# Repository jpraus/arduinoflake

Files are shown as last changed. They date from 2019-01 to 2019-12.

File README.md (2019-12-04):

# Arduinoflake

Arduinoflake is an awesome winter decoration that will light up every dark night. It is no ordinary decoration. This frozen looking beauty is Arduino compatible and can be programmed to do whatever you want to! It features a capacitive touch button which let you interact with it. Last but not least it is **open-source**.

Arduinoflakes

## Features

- 30 LEDs grouped into 18 independent segments
- touch button for interactions
- ATmega8 Arduino compatible microprocessor
- micro USB interface for programming (CH340 USB-to-UART)
- AVR ISP interface for bootloader flashing
- runs up to 12 hours on a single CR2032 battery

## Building your Arduinoflake

The easiest way how to get your own snowflake is to order a DIY kit on my [Tindie Store](https://www.tindie.com/products/jiripraus/arduinoflake/). Kit contains professionally manufactured PCBs by PCBway and all compatible components needed to assemble a fully functional Arduinoflake.

The second option is to manufacture the PCB and get all necessary parts yourself. Arduinoflake is Open-Source. [Schematic](doc/schematic_rev4.png) and [Gerber files](gerber/) are included in this repository. Don't forget to share your creation with me, I would love to see that!

### Board revisions history

- **rev1** - no dedicated touch IC
- **rev2** - public version without USB (2018)
- **rev3** - private beta with USB
- **rev4** - public version with USB (2019)

### Parts list

- ATmega8A TQF32
- TTP223 SOT23
- CH340E MSOP-10
- 18x bright white flat-top crystal clear LEDs
- 12x bright white 1206 SMD LEDs
- 18x 68Ω resistors
- 5x 100nF capacitors
- 50pF capacitor
- 10kΩ resistor
- 2x 1kΩ resistors
- micro USB connector
- CR2032 battery holder
- MSK-12C02 power switch

## Understanding Arduinoflake hardware

Arduinoflake consists of 30 white LEDs grouped into 18 segments. Each group is connected to one of the ATmega8 output pins and can be programmatically controlled.  The touch button is handled by standalone TTP223 integrated circuit and is connected to PD3 input pin with interrupt support.

<p align="center">
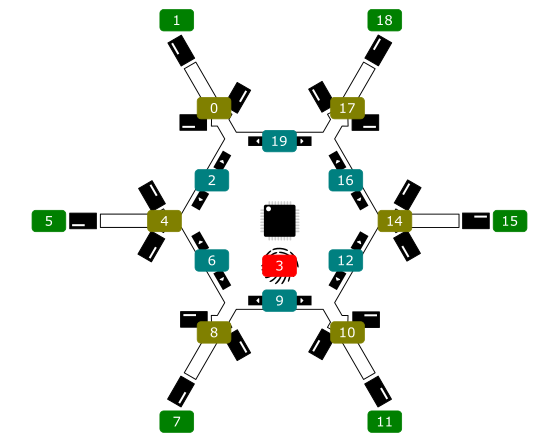
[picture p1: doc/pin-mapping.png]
  <br />
  <em>Arduinoflake LED groups to ATmega8 digital pins mapping</em>
</p>

## Connecting snowflake to the computer

### Installing MiniCore

Arduinoflake can be programmed using the Arduino IDE. However, the Atmega8 chip is not supported by default and you need to add the support first and configure it.

- Install [MCUdude/MiniCore](https://github.com/MCUdude/MiniCore#how-to-install) device library 
- Open **Tools > Boards** and select **ATmega8**
- Select **Tools > Clock > 8 MHz internal**
- Select **Tools > BOD > Disabled**
- Select **Tools > Compiler LTO > LTO disabled**
- Select **Tools > Bootloader > Yes (UART0)**

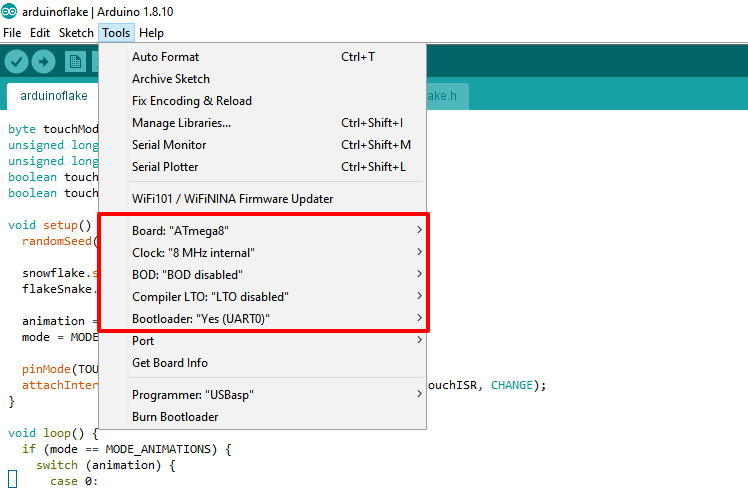
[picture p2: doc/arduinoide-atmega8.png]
Arduino IDE ATmega8


### Flashing the bootloader

If you purchased the kit from me, your chip already has a bootloader flashed and can be connected and programmed via USB - skip this part. If you started with a blank microprocessor you need special hardware to upload bootloader to the chip to be able to communicate via USB. If there is a problem with USB programming, it's also wise to try to flash the bootloader again.

#### USBasp

[USBasp](https://www.fischl.de/usbasp/) is a cheap $1 board that allows you to connect any ATmega chip with your computer via USB. Including Arduinoflake. It translates USB commands into AVR ISP commands that can program the processor.

There is an ISP interface in the left corner on the back of Arduinoflake. You can either use pogo pins if you have those or solder 6-pin header directly to the board to easily connect your ISP cable. Arduinoflake is both 3.3V and 5V tolerant.

<p align="center">
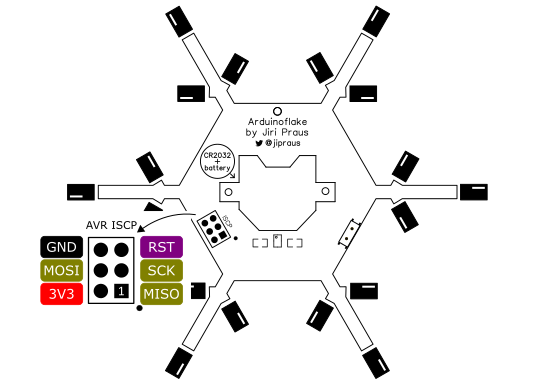
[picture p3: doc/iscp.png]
  <br />
  <em>AVR ISP programming interface</em>
</p>

#### Arduino as ISP (alternative to USBasp)

You can turn common Arduino UNO or any other Arduino board into programming hardware. its a bit messy, but does not require special hardware. [Read](https://www.arduino.cc/en/tutorial/arduinoISP) how to turn your Arduino UNO into a programmer. The rest is same as with USBasp.

#### Burn bootloader

Do you have your programmer set? Go now to Arduino IDE and with above settings run **Tools > Burn Bootloader**

### First upload

Checkout this repository and open [arduinoflake.ino](src/arduinoflake/arduinoflake.ino) project file. Connect your Arduinoflake to your computer via micro USB cable. Make sure you are using smart USB cable, some of the cables are power only and thus cannot transfer data at all. Select the port of your Arduinoflake, it should be the one that just appears. You might need to install a CH340 driver.

Run **Sketch > Upload**. You should get a sweet *'avrdude done. Thank you.'* message at the end of the console. Now you can make your own personalized Arduinoflake.

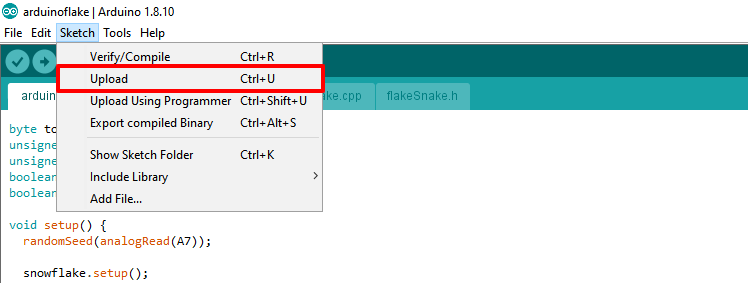
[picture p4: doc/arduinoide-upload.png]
Arduino IDE upload


## Getting started with the Arduinoflake library

Getting started with the Arduinoflake library
Arduinoflake comes with handy [canvas.cpp](src/arduinoflake/canvas.cpp) class which creates an abstraction over the Arduinoflake hardware. You will use it to paint your Arduinoflake with lights.

### Features

- LEDs are addressed with index (0-18)
- setup single LED
- setup range of LEDs
- power management
- software PWM for each LED (to be done)
- touch button abstraction (to be done)

### Constructor
```
CANVAS(byte numLedsAtOnce);
```
- **numLedsAtOnce** - power saving factor, number between 1-18, high number high power consumption but also brighther LEDs

### Basic functions
```
void setup()
```
Need to be called in project's setup() function to setup hardware.

```
void render()
```
Need to be called every 1ms in project's loop() function to be able toproperly control LEDs.

### Draw functions
```
void set(byte index, byte value);
```
Set brightness *value* to LED on *index*. Use LED_ON or LED_OFF constant for value.

```
void setByRange(byte fromIndex, byte toIndex, byte value);
```
Set brightness *value* to LEDs on indeces <*fromIndex*, *toIndex*). Use LED_ON or LED_OFF constant for value.

```
void clear();
```
Turn off all LEDs.

<p align="center">
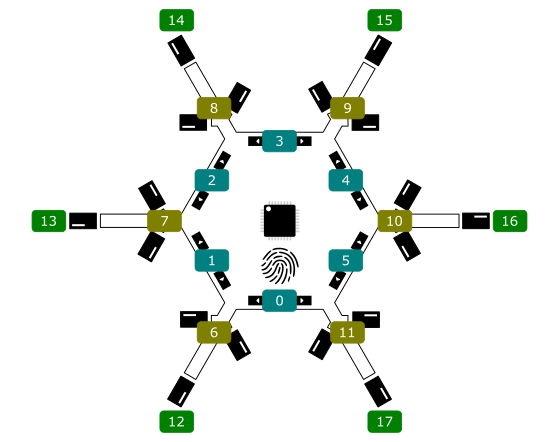
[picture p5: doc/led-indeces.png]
  <br />
  <em>Arduinoflake LED groups indexes used in library</em>
</p>

## Backlog

- [ ] Add touch button abstraction to hardware class
- [ ] Add support for PWM
- [ ] Add more animations

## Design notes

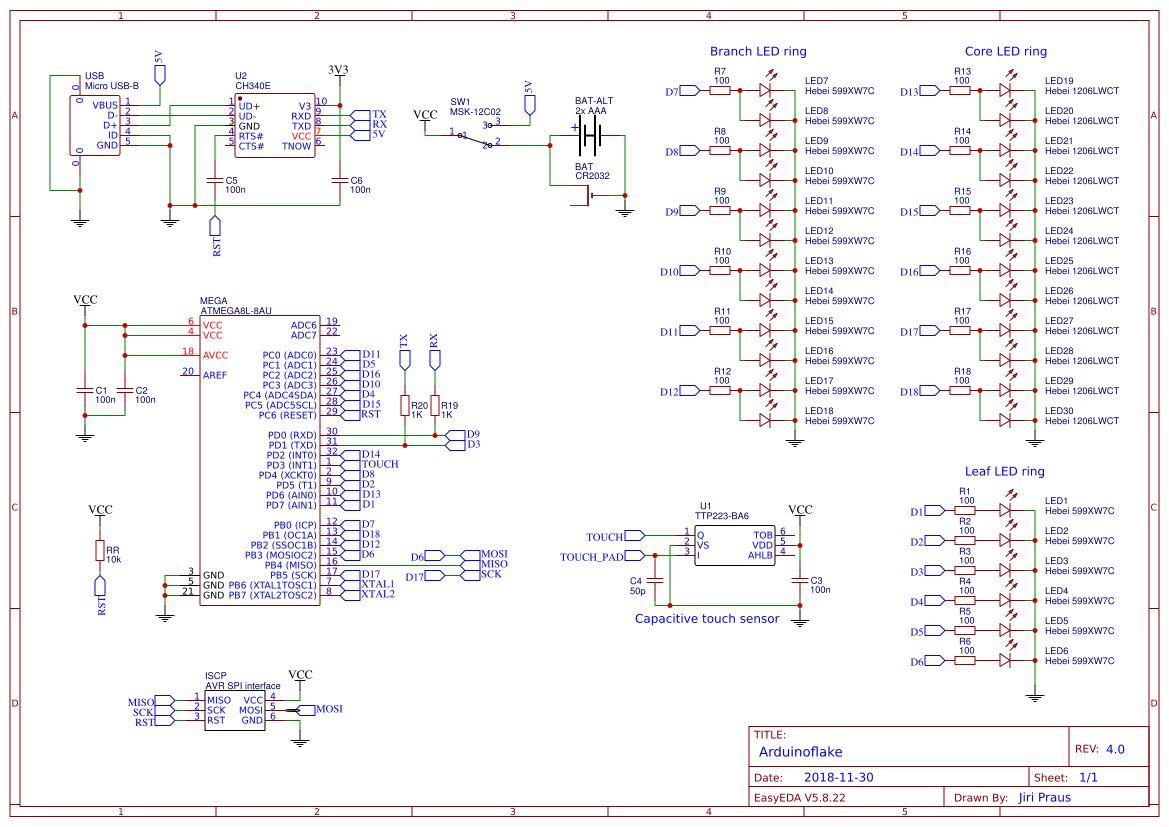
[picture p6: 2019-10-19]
doc/schematic_rev4.png

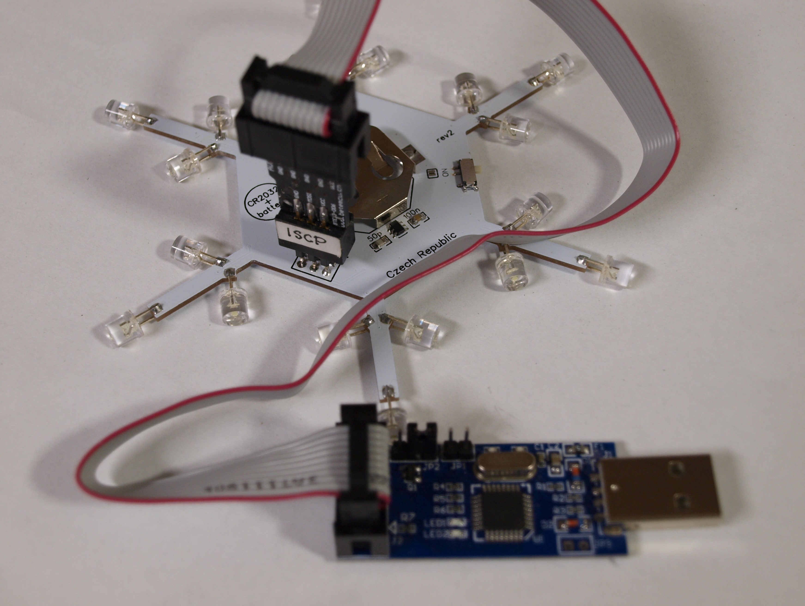
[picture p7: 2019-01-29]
doc/usbasp.JPG

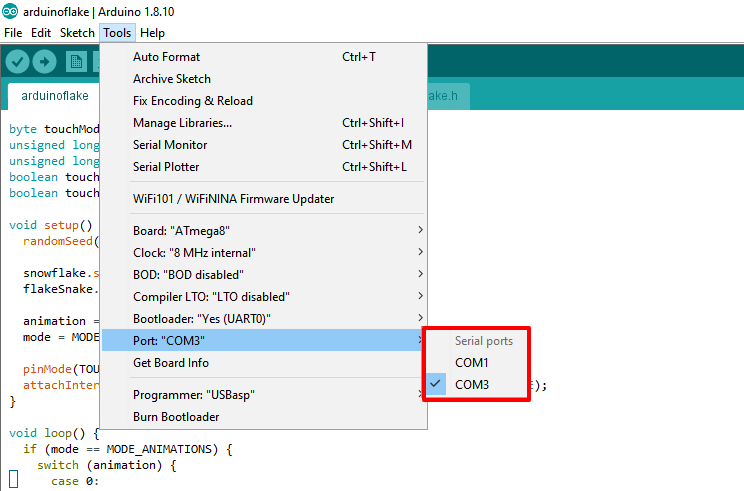
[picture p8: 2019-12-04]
doc/arduinoide-port.png

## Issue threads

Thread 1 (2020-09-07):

About burning bootloader and uploading "blink" example

jeansses, 2020-09-07:
hi，I really like your design, so I tried to make it myself, and I used "Arduino flake"_ Gerber of rev4. Zip "has found some problems. Please help me to deal with them. I used Arduino uno to upload the bootloader for arduinoflake. Arduino ide showed "upload succeeded" and the two LEDs on arduinoflake began to flash twice a second. I think the bootloader should have been successful, but then I continued to try to upload the "blink" sample program, but always prompted me "avrdude: stk500"_ getsync(): can't communicate with device: resp=0xfc

”For asynchronous messages, I use the connection mode of ISCP to arduinonuno (RST > > 10 MoSi > > 11 SCK > > 13 miso > > 12 GND > > GND VCC > > 3.3V

)
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

jeansses, 2020-09-07:
and tried every download mode in "programmer", and also tried to use micro USB cable through ch340. But the results are not correct upload procedures. Can you help me?

jeansses, 2020-09-07:
@jpraus

jpraus, 2020-09-10:
Hi! What hardware are you using? Did you build your own hardware? I experienced the same issue with ATmega8 not being genuine. It's internal close are not running in precise interval. You can try to flash it with bootloader with 1MHz clock and try to upload. If it passed that the Atmega8 clock is problem.

jeansses, 2020-09-10:
Hello, I use your rev4 version of PCB chip atmega8l. I searched some information and suspected it was a clock problem. Thank you for your question. Next, I will try to use the 1MHz clock, restart the program, and then try to upload. I'll give you feedback on my running results later. Thank you again for your help! brother

---Original---
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

jeansses, 2020-09-16:
According to your method, I chose the internal 1 MHz clock when burning the boot program, but I still failed to upload. At the same time, after the upload failure, the LED will flash like the video in the attachment. I don't know what to do next。

------------------ 原始邮件 ------------------
发件人:                                                                                                                        "jpraus/arduinoflake"                                                                                    <notifications@github.com&gt;;
发送时间:&nbsp;2020年9月10日(星期四) 晚上8:48
收件人:&nbsp;"jpraus/arduinoflake"<arduinoflake@noreply.github.com&gt;;
抄送:&nbsp;"‭"<269263336@qq.com&gt;;"Author"<author@noreply.github.com&gt;;
主题:&nbsp;Re: [jpraus/arduinoflake] About burning bootloader and uploading "blink" example (#1)

Hi! What hardware are you using? Did you build your own hardware? I experienced the same issue with ATmega8 not being genuine. It's internal close are not running in precise interval. You can try to flash it with bootloader with 1MHz clock and try to upload. If it passed that the Atmega8 clock is problem.

—
You are receiving this because you authored the thread.
Reply to this email directly, view it on GitHub, or unsubscribe.

jeansses, 2020-09-24:
> 嗨！您正在使用什么硬件？您是否构建了自己的硬件？我遇到了同样的问题，但ATmega8并不是真正的。它的内部关闭没有以精确的间隔运行。您可以尝试使用引导加载程序以1MHz的时钟对其进行刷新，然后尝试上传。如果通过，说明Atmega8时钟有问题。

I still failed according to your method, I even bought ISCP downloader now, but still can't solve the problem.. I feel terrible

jeansses, 2020-10-10:
> Hi! What hardware are you using? Did you build your own hardware? I experienced the same issue with ATmega8 not being genuine. It's internal close are not running in precise interval. You can try to flash it with bootloader with 1MHz clock and try to upload. If it passed that the Atmega8 clock is problem.

Let me tell you a good news. I finally solved this problem. The solution is that I changed the chip again and found that it can be used normally. I suspect that the chip was broken down during burning. Anyway, thank you very much for your design. I like it very much. I will give it to my girlfriend.

jeansses, 2020-10-10:
> Hi! What hardware are you using? Did you build your own hardware? I experienced the same issue with ATmega8 not being genuine. It's internal close are not running in precise interval. You can try to flash it with bootloader with 1MHz clock and try to upload. If it passed that the Atmega8 clock is problem.
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

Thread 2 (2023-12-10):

fuse bit settings

Creo2005, 2023-12-10:
Please let me know what should the fuse bit settings be to use the internal crystal (1 or 8 MHz). Because I set the fuse incorrectly and now usbasp programmer sees the atmega8 only with external cristal. I want to remove the external crystal. Now I can't set the fuse correctly to work without external cristal and i whant flash the boot and them flash firmware via usb from Arduino IDE. Thanks.

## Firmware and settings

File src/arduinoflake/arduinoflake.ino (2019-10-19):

#include "canvas.h"
#include "flakeSnake.h"

// 2 for CR2032, 5 for 2xAAA
#define BATTERY_LIFETIME 2 // from 1 (~11mA) to 18 (~80mA); 1 - longest lifetime, 18 - shortest lifetime

#define MODE_ANIMATIONS 0
#define MODE_SNAKE 1

#define TOUCH_SENSOR_PIN 3
#define TOUCH_MODE_ON_UP 0 // recognize touch on touch up
#define TOUCH_MODE_ON_DOWN 1 // recognize touch on touch down

CANVAS snowflake(BATTERY_LIFETIME);
FLAKE_SNAKE flakeSnake(&snowflake);

byte mode = MODE_ANIMATIONS;
bool animationChanged = true;
byte animation = 0;
byte frame = 0;

byte touchMode = TOUCH_MODE_ON_UP;
unsigned long touchStartMs = 0;
unsigned long touchDuration = 0;
boolean touched = false;
boolean touchHandled = true;

void setup() {
  randomSeed(analogRead(A7));
  
  snowflake.setup();
  flakeSnake.restart();

  animation = random(0, 6);
  mode = MODE_ANIMATIONS;

  pinMode(TOUCH_SENSOR_PIN, INPUT);
  attachInterrupt(digitalPinToInterrupt(TOUCH_SENSOR_PIN), touchISR, CHANGE);
}

void loop() {
  if (mode == MODE_ANIMATIONS) {
    switch (animation) {
      case 0:
        randomAnimation();
        break;
      case 1:
        glowAnimation();
        break;
      case 2:
        loopAnimation();
        break;
      case 3:
        circleAnimation(true);
        break;
      case 4:
        fanAnimation();
        break;
      case 5:
        circleAnimation(false);
        break;
      default:
        animation = 0;
        break;
    }
  }
  else if (mode == MODE_SNAKE) {
    flakeSnake.update(frame);
  }

  snowflake.render();
  frame ++;

  // handle touch
  if (touched && !touchHandled) {
    if (mode == MODE_ANIMATIONS && touchDuration > 1000) { // long touch to change to snake
      frame = 0;
      mode = MODE_SNAKE;
      flakeSnake.restart();
      touchMode = TOUCH_MODE_ON_DOWN;
    }
    else if (mode == MODE_ANIMATIONS) {
      frame = 0;
      animation ++;
      animationChanged = true;
      snowflake.clear();
    }
    else if (mode == MODE_SNAKE) {
      flakeSnake.handleTouch(); 
    }

    touchHandled = true;
  }
}


void touchISR() {
  byte touchOn = digitalRead(TOUCH_SENSOR_PIN);
  if (touched && !touchHandled) {
    return; // previous touch was not handled yet.
  }
  if (touchOn == HIGH) {
    if (touchMode == TOUCH_MODE_ON_DOWN) {
      touched = true;
      touchHandled = false;
    }
    else if (touchMode == TOUCH_MODE_ON_UP) {
      touchStartMs = millis();
      touchDuration = 0;
    }
  }
  else if (touchStartMs > 0 && touchMode == TOUCH_MODE_ON_UP) {
    touchDuration = millis() - touchStartMs;
    touchStartMs = 0;
    touched = true;
    touchHandled = false;
  }
}

/**
 * Glow animation - fully lit snowflake
 */
void glowAnimation() {
  if (animationChanged) {
    snowflake.setByRange(0, 18, 128);
    animationChanged = false;
  }
}

/**
 * Circles animation - circles from center to the edges
 */
byte circleIndex = 0;

void circleAnimation(bool bounce) {
  if (animationChanged) {
    circleIndex = 0;
    animationChanged = false;
  }

  if (frame < 255) { // speed of animation
    return;
  }
  frame = 0;

  snowflake.clear();
  switch (circleIndex) {
    case 0:
      snowflake.setByRange(0, 6, LED_ON);
      break;
    case 1:
    case 3:
      snowflake.setByRange(6, 12, LED_ON);
      break;
    case 2:
      snowflake.setByRange(12, 18, LED_ON);
      break;
  }

  circleIndex ++;
  if (circleIndex == 3 && !bounce || circleIndex >= 4) {
    circleIndex = 0;
  }
}

/**
 * Snake animation - 3 pixels snake running around
 */
byte snakeState = 0;

bool snakeAnimation() {
  if (animationChanged) {
    snakeState = 0;
    animationChanged = false;
  }
  
  if (frame < 150) { // speed of animation
    return false;
  }
  frame = 0;

  for (int i = 0; i < 18; i ++) { 
    snowflake.set(i, (i >= snakeState && i < snakeState + 3) ? LED_ON : LED_OFF);
  }
  if (snakeState >= 16) {
    for (int i = 6; i < 12; i ++) { 
      snowflake.set(i, (i >= snakeState - 12 && i < snakeState - 9) ? LED_ON : LED_OFF);
    }
  }
  if (snakeState >= 22) {
    snowflake.set(0, LED_ON);
  }
  if (snakeState >= 23) {
    snowflake.set(1, LED_ON);
  }
  if (snakeState >= 24) {
    snowflake.set(2, LED_ON);
  }

  snakeState += 1;
  if (snakeState >= 24) {
    snakeState = 0;
    return true; // finsihed
  }

  return false;
}

/**
 * Loop animation - circling on and off
 */
byte loopState = 0;

bool loopAnimation() {
  if (animationChanged) {
    loopState = 0;
    animationChanged = false;
  }
  
  if (frame < 150) { // speed of animation
    return false;
  }
  frame = 0;

  if (loopState < 6) {
    for (int i = loopState; i < 18; i += 6) {
      snowflake.set(i, LED_ON);
    }
  }
  else {
    for (int i = loopState - 6; i < 18; i += 6) {
      snowflake.set(i, LED_OFF);
    }
  }

  loopState += 1;
  if (loopState >= 12) {
    loopState = 0;
    return true; // finsihed
  }

  return false;
}


/**
 * Fan animation - spining rotor of a fan
 */
byte fanIndex = 0;

void fanAnimation() {
  if (animationChanged) {
    fanIndex = 0;
    animationChanged = false;
  }

  if (frame < 90) { // speed of animation
    return;
  }
  frame = 0;

  snowflake.clear();
  for (byte i = fanIndex; i < 18; i += 3) {
    snowflake.set(i, LED_ON);
  }

  fanIndex ++;
  if (fanIndex >= 3) {
    fanIndex = 0;
  }
}

/**
 * Random animation - one random LED at the time
 */
byte lastRandom = 0;

void randomAnimation() {
  if (animationChanged) {
    lastRandom = 0;
    animationChanged = false;
  }

  if (frame < 10) { // speed of animation
    return;
  }
  frame = 0;

  snowflake.set(lastRandom, LED_OFF);
  lastRandom = random(0, 18);
  snowflake.set(lastRandom, LED_ON);
}

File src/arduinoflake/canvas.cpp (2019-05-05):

#include "canvas.h"

// TODO: move this somewhere else
byte ledPins[] = {
  9, 6, 2, 19, 16, 13, // inner (12 -> 13 rev4)
  8, 4, 0, 17, 14, 10, // middle
  7, 5, 1, 18, 15, 11  // outer
};

CANVAS::CANVAS(byte _numLedsAtOnce) {
  numLedsAtOnce = _numLedsAtOnce;
  for (int i = 0; i < LEDS_COUNT; i++) {
    ledState[i] = 0;
  }
}

void CANVAS::setup() {
  for (int i = 0; i < LEDS_COUNT; i++) {
    pinMode(ledPins[i], OUTPUT);
  }
}

void CANVAS::set(byte index, byte value) {
  ledState[index] = value;
}

void CANVAS::setByRange(byte fromIndex, byte toIndex, byte value) {
  for (byte i = fromIndex; i < toIndex; i++) {
    ledState[i] = value;
  }
}

void CANVAS::clear() {
  for (int i = 0; i < LEDS_COUNT; i++) {
    ledState[i] = LED_OFF; 
  }
}

void CANVAS::render() {
  byte origFrame = ledFrame;
  byte ledFrameTmp = ledFrame;

  byte counter = numLedsAtOnce;
  do {
    if (ledState[ledFrameTmp] > 0) {
      digitalWrite(ledPins[ledFrameTmp], HIGH);
      counter--;
    }
    ledFrameTmp++;
    if (ledFrameTmp == LEDS_COUNT) {
      ledFrameTmp = 0;
    }
  } while (ledFrameTmp != origFrame && counter > 0); // try to render up to counter

  delayMicroseconds(1024);

  counter = numLedsAtOnce;
  do {
    if (ledState[ledFrame] > 0) {
      digitalWrite(ledPins[ledFrame], LOW);
      counter--;
    }
    ledFrame++;
    if (ledFrame == LEDS_COUNT) {
      ledFrame = 0;
    }
  } while (ledFrame != origFrame && counter > 0); // try to render up to counter
}

/*
void renderByPwm() {
  // 0 off
  // 1-127 PWM (from off to fully lit)
  // 128 fully lit
  // 129-255 PWM reversed (from fully lit to off)

  if (ledState[_ledFrame] == LED_ON) { // fully lit
    digitalWrite(ledPins[_ledFrame], HIGH);
    delayMicroseconds(1024);
    digitalWrite(ledPins[_ledFrame], LOW);
  }
  else { // pseudo PWM (dimmed)
    int state = ledState[_ledFrame];
    if (state > LED_ON) {
      state = 255 - state; // reversed to 1-128
    }
    state = state << 3; // mapped to 0 - 1024 us

    digitalWrite(ledPins[_ledFrame], HIGH);
    delayMicroseconds(state);
    digitalWrite(ledPins[_ledFrame], LOW);
    delayMicroseconds(1024 - state);
  }

  _ledFrame += 1;
  if (_ledFrame >= 18) {
    _ledFrame = 0;
  }
}
*/

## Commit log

2018-12-18 added gerber files, images and changed license
    [Gerber_BoardOutline.GKO, Gerber_BottomLayer.GBL, Gerber_BottomPasteMaskLayer.GBP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]
2018-12-21 implemented touch button
2019-01-11 improved on battery version, end of revision 1
2019-01-12 adapted for rev2 arduinoflake board
2019-01-12 fixed fan animation
2019-01-29 schematic and iscp description
2019-01-29 Arduino IDE screenshots
2019-02-13 added lastest Gerber files
    [Gerber_BoardOutline.GKO, Gerber_BottomLayer.GBL, Gerber_BottomPasteMaskLayer.GBP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]
2019-03-15 removed rev3 board
2019-03-24 revision 4 of the board with built-in USB
2019-04-13 final rev4 boards with USB
2019-10-19 schematic for rev4 board
